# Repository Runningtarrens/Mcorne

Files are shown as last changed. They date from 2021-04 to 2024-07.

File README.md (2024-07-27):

# Mcorne legacy
28816_Mcorne_Banner

This is the Repository for a Magnetic Case for the Corne keyboard.



Content:

* Preface
* The case
* Bill of Materials
* How to print
* Files
* Tangented
* More Pics
* Legend
* License

# Preface

Rework of the documentation on a special page: https://runningtarrens.github.io/Mcorne/

If you build a lot of keyboards or repair them, you know the hassle of having to open the cases, screw/ unscrew and taking apart the whole thing everytime you need to reflow a solder point, an led or maybe even just reset the MCU. Also for any corne build youll need to have about 20 screws and 5 standoffs per half to just keep the halfs together. With the Mcorne you dont need to unscrew anything to access the PCB or any screw or standoff to use this case. The Case supports magnetic tenting legs and provides tenting holes for other tenting methods.

Feel free to join the Discord Server, if you have questions about the case or just want to have a chat: https://discord.gg/TRQFN7fyU5

# The Case

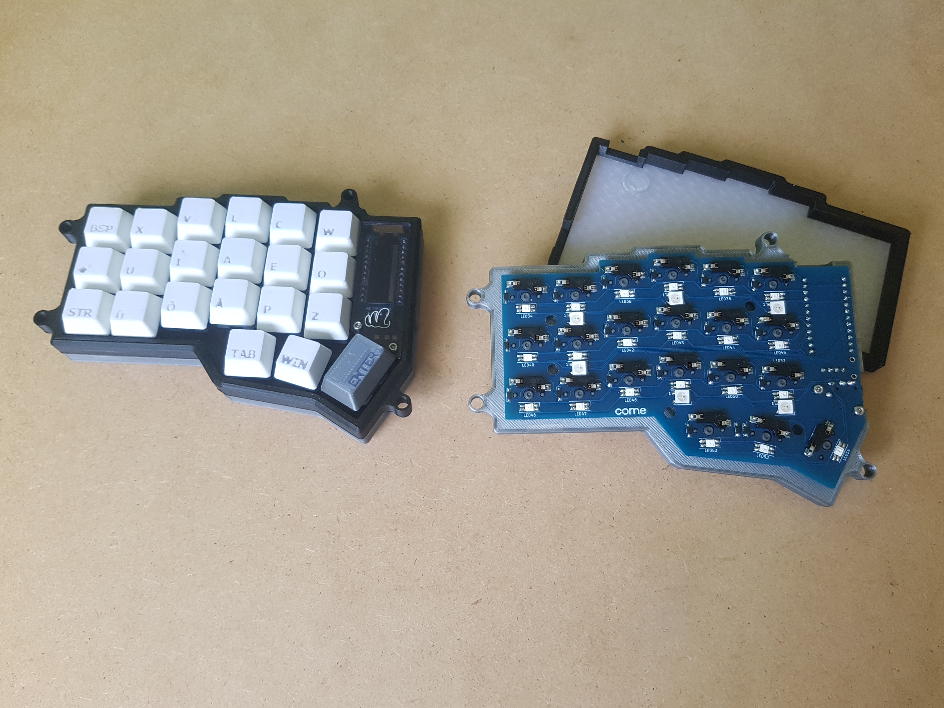
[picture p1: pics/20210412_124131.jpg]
MagneticCorne2

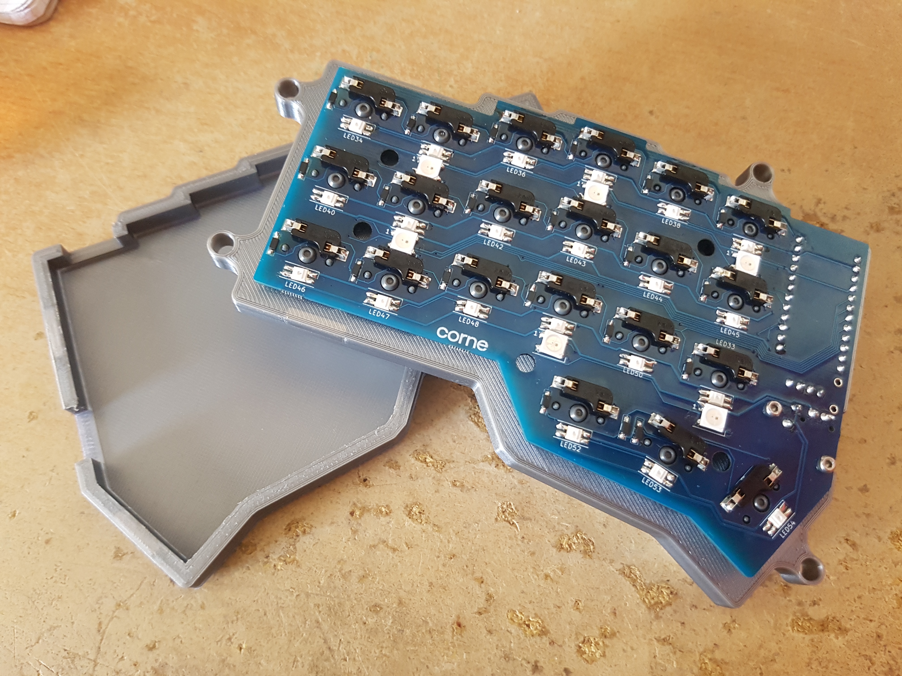
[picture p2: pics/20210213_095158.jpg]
MagneticCorne3

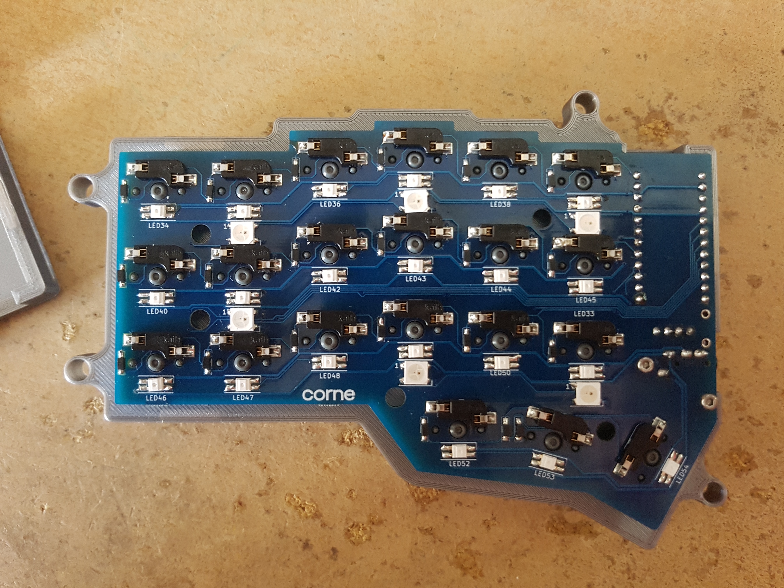
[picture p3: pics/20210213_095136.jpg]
MagneticCorne4


# Bill of Materials

To print this case youll need:
* about 120 gramms of Filament
* 16 Neodymium Magnets (14mm x 4mm x 2,5mm)
* (Optional) 4 Neodymium Magnets round (10mm x 1mm)

Getting the right Magnets can be Hard. Hier are a list of sources i could find or people provided me:

* Europe:
* USA: [Ebay.com](https://www.ebay.com/itm/255362762463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)

# How to print
 
 I always print in PLA, but you can use any filament for the case. ABS/ASA and Filament that require an enclosure are difficult to work with, because if you want to put the magnets in, you have to open the enclosure and might be having problems with warping or cracked prints because of that.

## Slicing

### Settings for the Print:

* 0.10 layer hight
* 3 Parimeters
* 3 Top and Bottom layers
* 15% Infill
* 205°C Filament temp
* 60°C Bed Temp

### Getting the magnets in

To get the magnets in, the M600 command is used. The printer makes a pause. While the print is pause, the magnets can be put into the pockets. Its important that you check and double check the polarity of the magnets, so that the halfs stick to each other and dont repel each other. The holes are tight but have a bit of tolerance, it can be a bit of work getting the magnets in, depending on how accurate your printer is.

### Top
The print is paused on the top half after the 42 layer or 4.2mm hight.
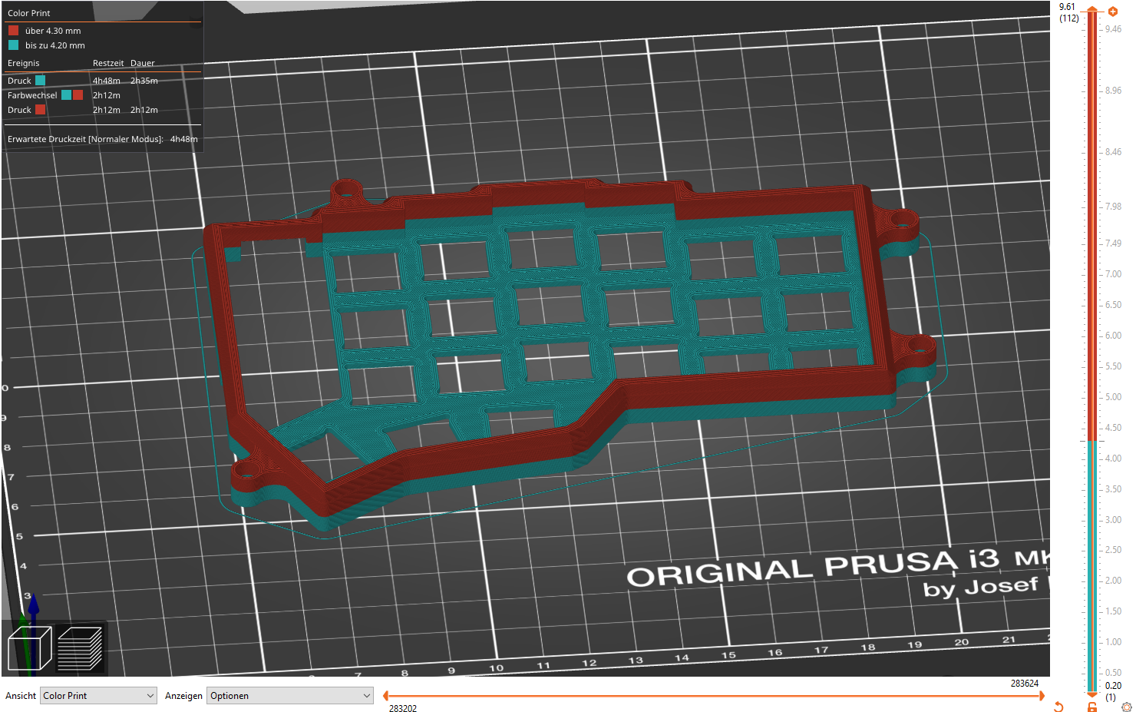
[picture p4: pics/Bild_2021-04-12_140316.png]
MagneticCorne5


#### Position of the Pockets for the Magnets
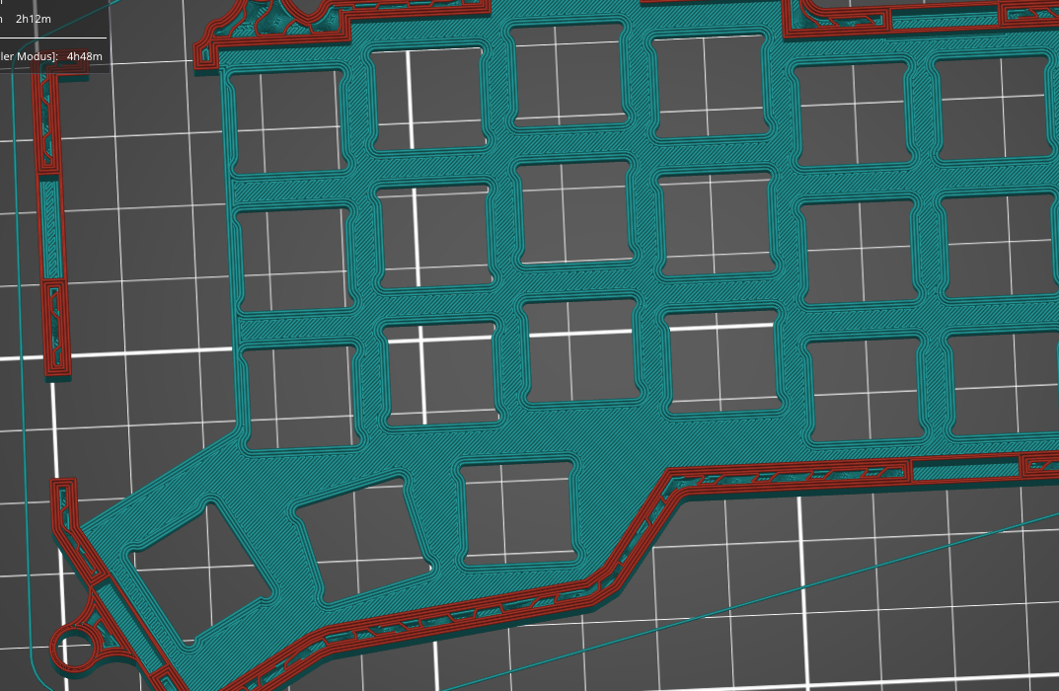
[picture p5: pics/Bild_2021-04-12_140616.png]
MagneticCorne6


### Bottom

The Bottom part is a bit more complex. It has, if you choose magnetig tenting and a transparent basis, 3 pauses. 2 to get the magnets in and 1 to just change the filament. If you dont want magnetic tenting and dont want another colour for the top part, youll only need one pause for the magnets.

#### Overview of the Part.

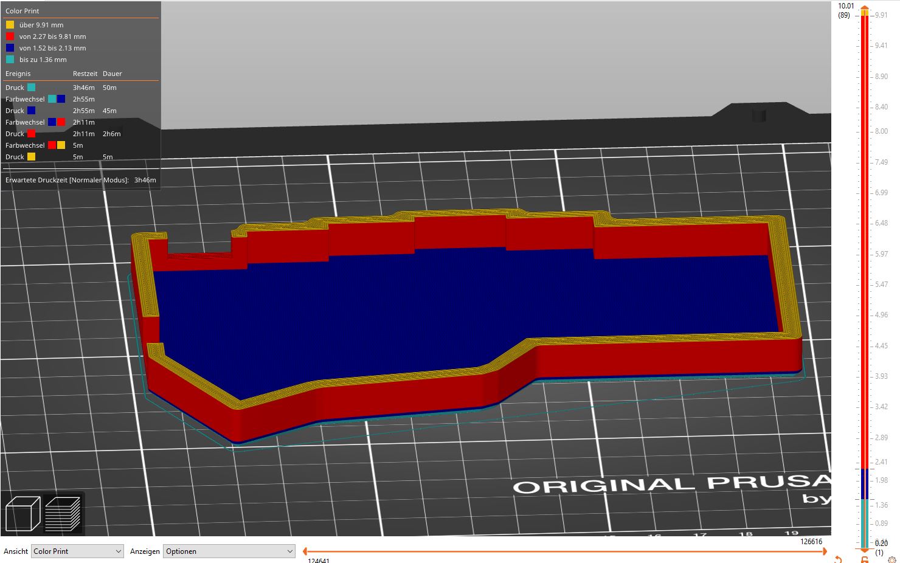
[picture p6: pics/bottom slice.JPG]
MagneticCorne7


#### First pause for the round magnets needed for the tenting

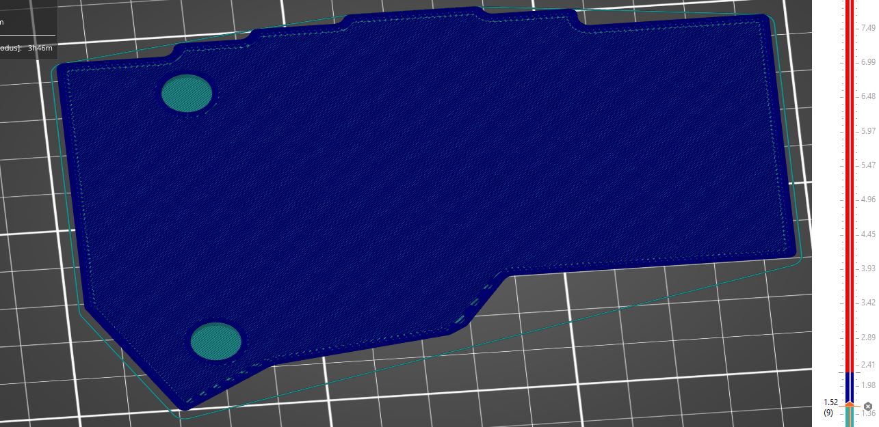
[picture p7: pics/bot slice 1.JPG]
MagneticCorne8


#### Second pause to change the filament (different colour)

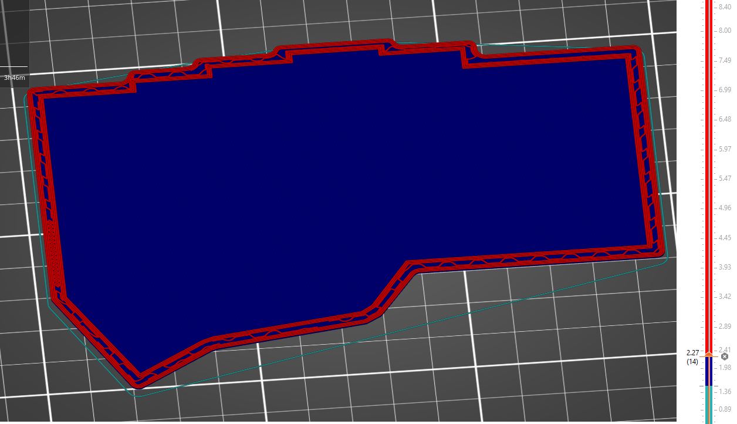
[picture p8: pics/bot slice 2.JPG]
MagneticCorne9


#### Third pause for the magnets to close the case

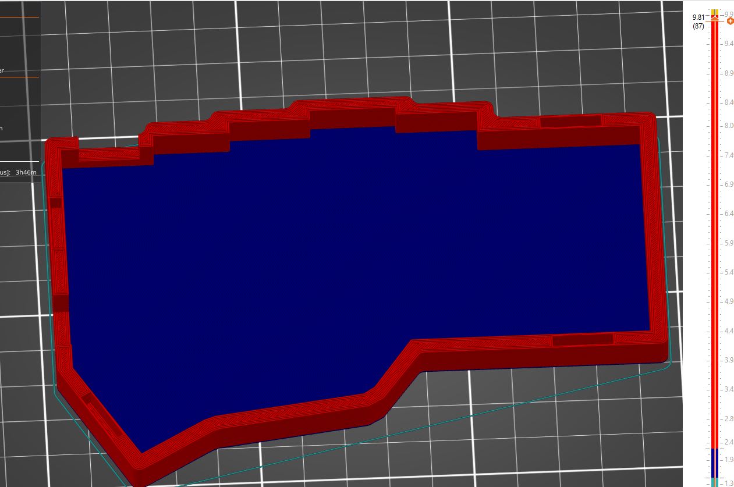
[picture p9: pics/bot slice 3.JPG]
MagneticCorne10


### Tenting Legs

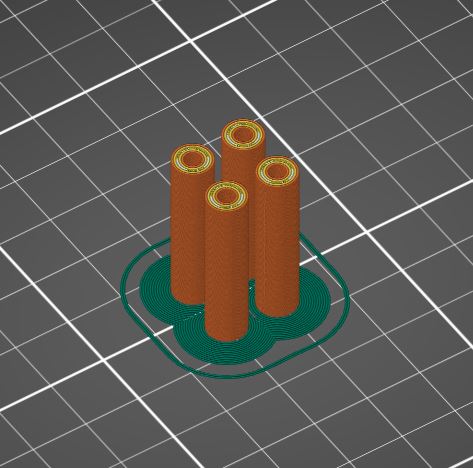
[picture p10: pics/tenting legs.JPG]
MagneticTentingLegs


Print 4 of them upright. But you need a prim to have enough surface that sticks to the build plate or it will get loose while printing.

# Files

## latest files

* corne split_bot_rechts_v4.stl
* corne split_top_right_reinforced_tentless_v4.stl
* corne split_top_right_reinforced_v4.stl
* magnet_tenting_30mm.stl

Version v4 is the latest for the case. I made some corrections so the inner keys ( T and Z dont scratch on the case).
I only uploaded the right side as .stl but you can just mirror it in your slicer software to get the left version of it. 

The .stl are to slice yourself. (There are also .3mf files which are already dialed in and provide the exact settings i use.).
The .3mf are in rework for now.

# Tangented

* Magnetic tenting legs - Added to the files directory
* Mcorne Travel Case - Added to the Travel Case directory
* Keycaps - soon

# More Pics

MagneticCornegif1
MagneticCornegif2

#### Bottom

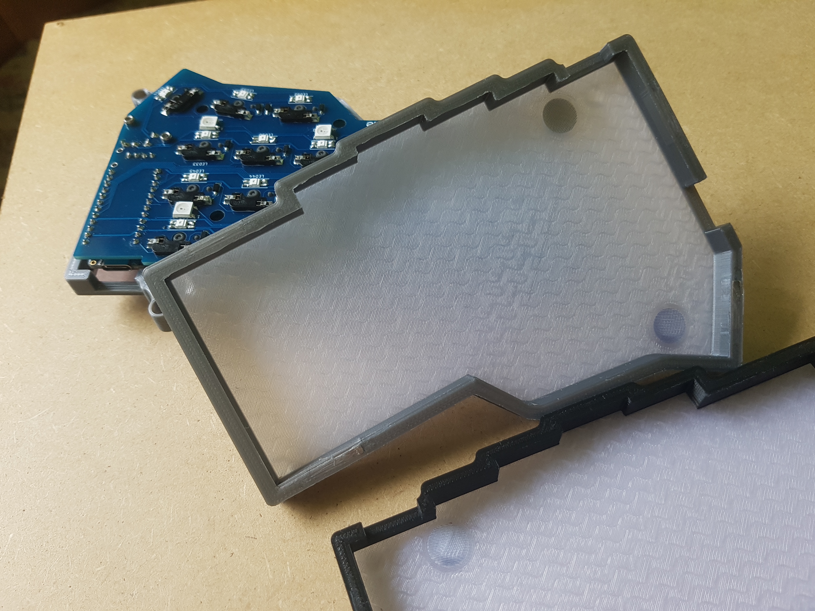
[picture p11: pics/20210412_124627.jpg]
MagneticCorne11


#### Top underside

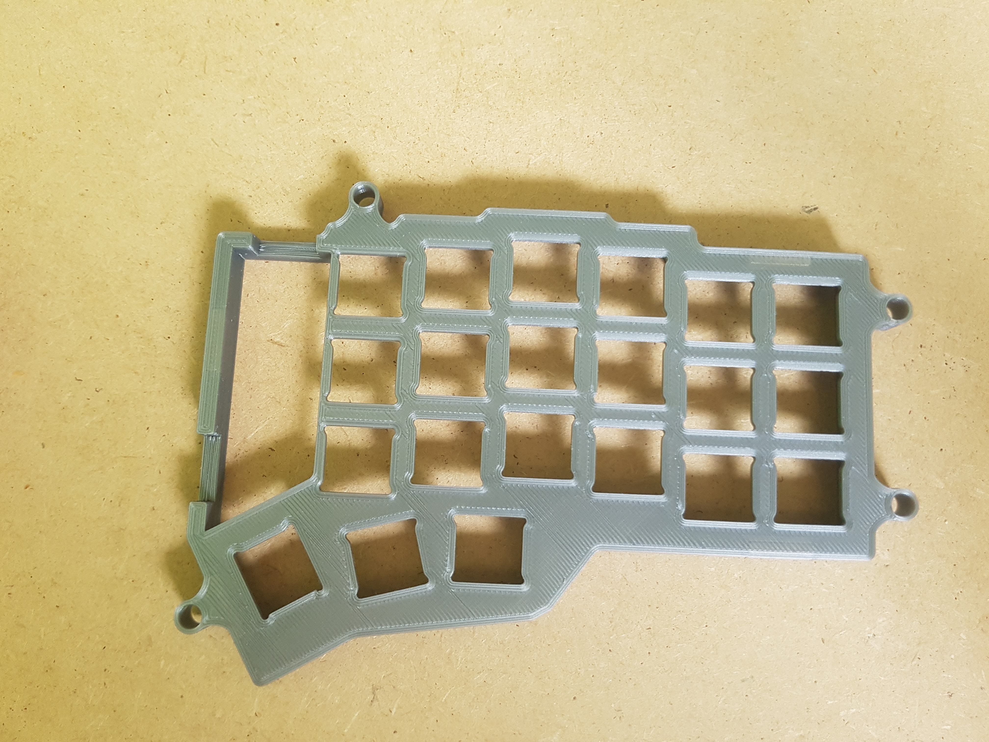
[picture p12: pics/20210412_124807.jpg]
MagneticCorne12


#### Top upside

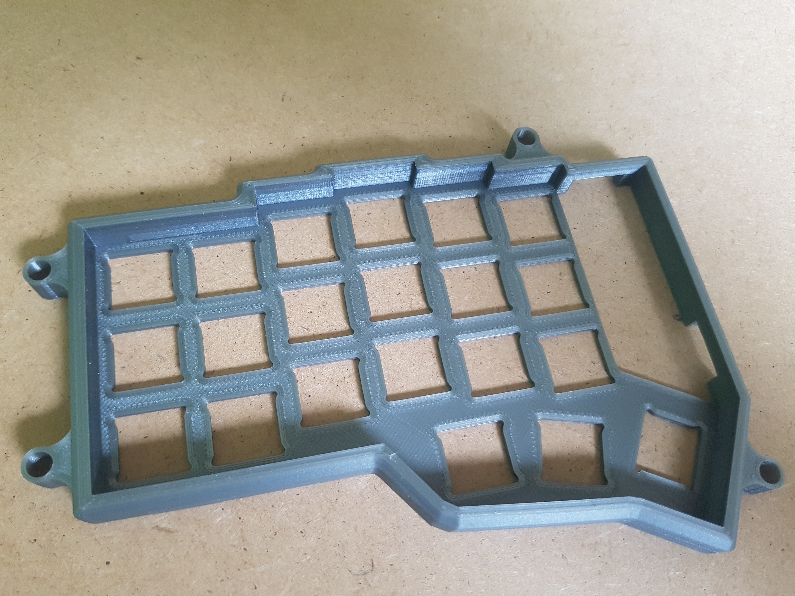
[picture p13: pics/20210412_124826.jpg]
MagneticCorne13


#### USB Port

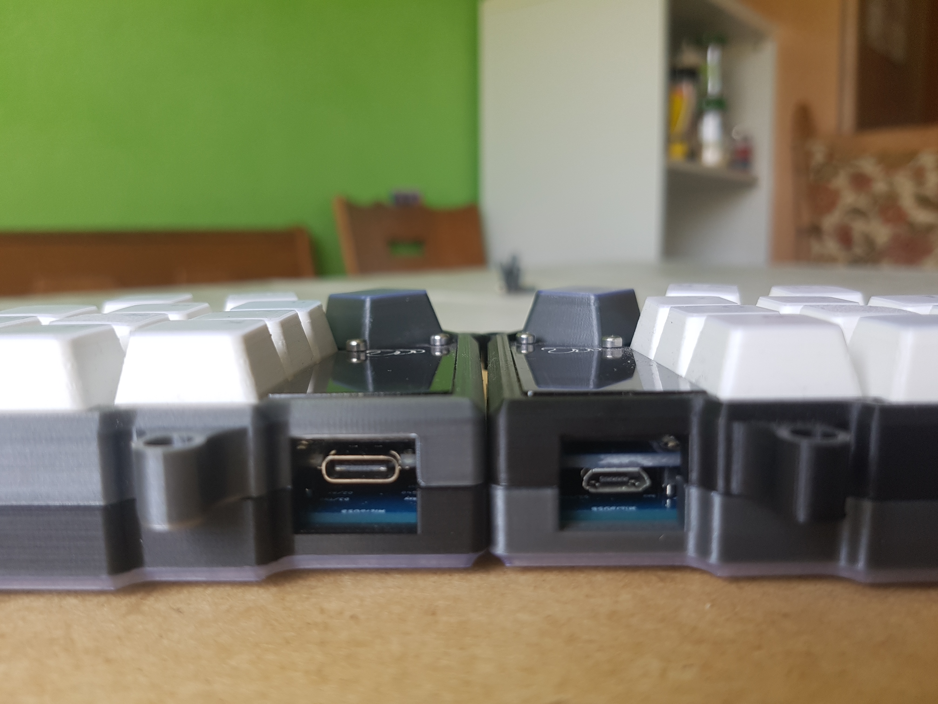
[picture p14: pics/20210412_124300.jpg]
MagneticCorne14


#### TRS Port

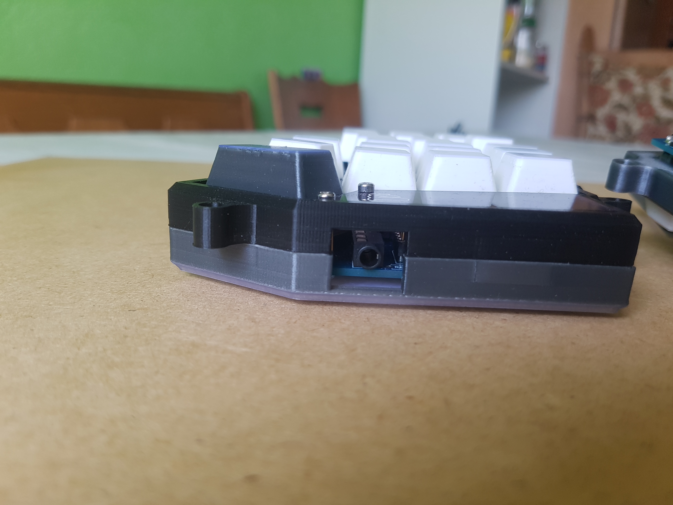
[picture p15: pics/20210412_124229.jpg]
MagneticCorne15


#### Detail view 

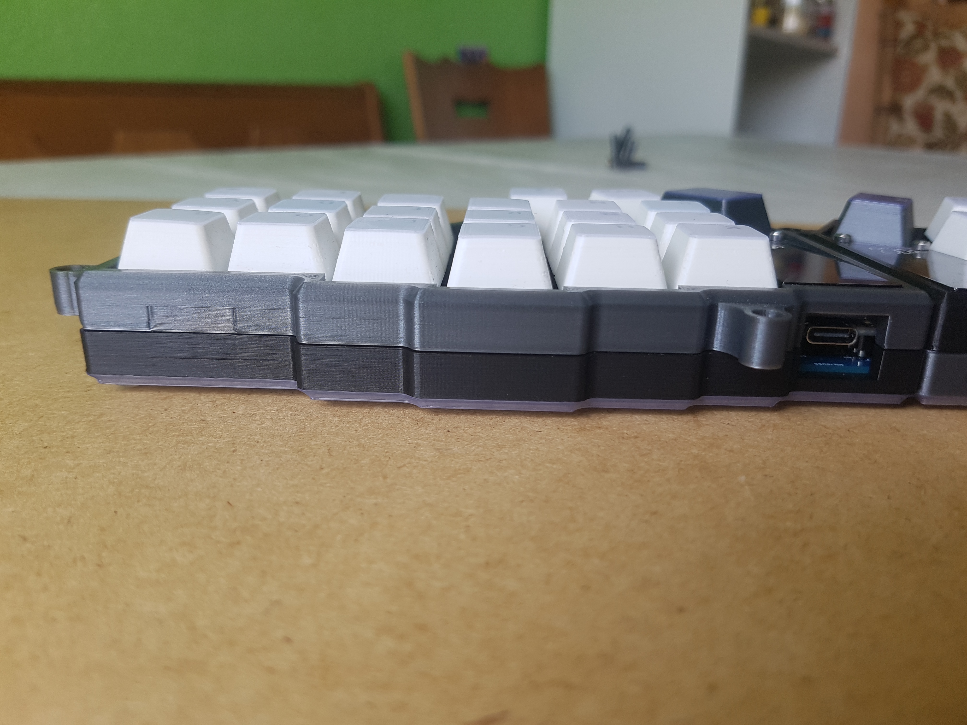
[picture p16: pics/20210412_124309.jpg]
MagneticCorne16


#### Detail view close up

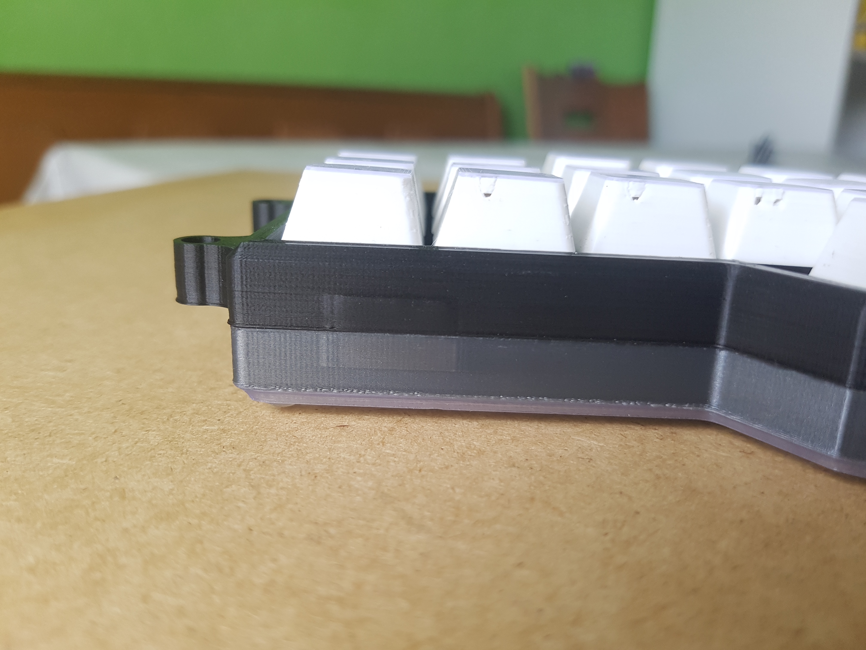
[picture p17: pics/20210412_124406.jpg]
MagneticCorne17


# Legend

* MCU = Microcontroller unit

# License

Print and modify all you want, but please dont sell my desgin (digital or printed).

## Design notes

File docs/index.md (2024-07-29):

# Welcome to Mcorne

28816_Mcorne_Banner

This is the Page for the Magnetic Case family for the Corne keyboard. There are different versions, so its easy to lose track of all the different versions or even to find the right one for your Corne and intented use case. So here is a overview with a quick summary of the features of the different cases and links to the different repositories.

## Preface

If you build a lot of keyboards or repair them, you know the hassle of having to open the cases, screw/ unscrew and taking apart the whole thing everytime you need to reflow a solder point, an led or maybe even just reset the MCU. Also for any corne build youll need to have about 20 screws and 5 standoffs per half to just keep the halfs together. The Mcorne doesnt need to be unscrewed to access the PCB or any screw or standoff to use this case. The Mcorne supports magnetic tenting legs and provides tenting holes for other tenting methods.

Feel free to join the Discord Server, if you have questions about the case or just want to have a chat: [Discord](https://discord.gg/TRQFN7fyU5)

!!! example "Disclaimer"

    To be able to print these cases you need a FDM printer. SLS or Resin printers wont work. Also your Printer firmware needs to support the pause feature to allow you to place the magnets in the pockets of the case. Most slicers and firewares use the M600 command.

## Commands

* `mkdocs new [dir-name]` - Create a new project.
* `mkdocs serve` - Start the live-reloading docs server.
* `mkdocs build` - Build the documentation site.
* `mkdocs -h` - Print help message and exit.

## Project layout

    mkdocs.yml    # The configuration file.
    docs/
        index.md  # The documentation homepage.
        ...       # Other markdown pages, images and other files.

This is the Repository for a Magnetic Case for the Corne keyboard.



This is the Repository for a Magnetic Case family for the Corne keyboard. There are 5 different version, so its easy to lose track of all the different versions or even to find the rigth one for your Corne and intented use case. So here is a overview with a quick summary of the features of the different cases and links to the different repositories.

Content:

* Preface
* The case
* Bill of Materials
* How to print
* Files
* Tangented
* More Pics
* Legend
* License

# Preface

Rework of the documentation on a special page: https://runningtarrens.github.io/Mcorne/

If you build a lot of keyboards or repair them, you know the hassle of having to open the cases, screw/ unscrew and taking apart the whole thing everytime you need to reflow a solder point, an led or maybe even just reset the MCU. Also for any corne build youll need to have about 20 screws and 5 standoffs per half to just keep the halfs together. With the Mcorne you dont need to unscrew anything to access the PCB or any screw or standoff to use this case. The Case supports magnetic tenting legs and provides tenting holes for other tenting methods.

Feel free to join the Discord Server, if you have questions about the case or just want to have a chat: https://discord.gg/TRQFN7fyU5

# The Case

MagneticCorne2
MagneticCorne3
MagneticCorne4

# Bill of Materials

To print this case youll need:
* about 120 gramms of Filament
* 16 Neodymium Magnets (14mm x 4mm x 2,5mm)
* (Optional) 4 Neodymium Magnets round (10mm x 1mm)

Getting the right Magnets can be Hard. Hier are a list of sources i could find or people provided me:

* Europe:
* USA: [Ebay.com](https://www.ebay.com/itm/255362762463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)

# How to print
 
 I always print in PLA, but you can use any filament for the case. ABS/ASA and Filament that require an enclosure are difficult to work with, because if you want to put the magnets in, you have to open the enclosure and might be having problems with warping or cracked prints because of that.

## Slicing

### Settings for the Print:

* 0.10 layer hight
* 3 Parimeters
* 3 Top and Bottom layers
* 15% Infill
* 205°C Filament temp
* 60°C Bed Temp

### Getting the magnets in

To get the magnets in, the M600 command is used. The printer makes a pause. While the print is pause, the magnets can be put into the pockets. Its important that you check and double check the polarity of the magnets, so that the halfs stick to each other and dont repel each other. The holes are tight but have a bit of tolerance, it can be a bit of work getting the magnets in, depending on how accurate your printer is.

### Top
The print is paused on the top half after the 42 layer or 4.2mm hight.
MagneticCorne5

#### Position of the Pockets for the Magnets
MagneticCorne6

### Bottom

The Bottom part is a bit more complex. It has, if you choose magnetig tenting and a transparent basis, 3 pauses. 2 to get the magnets in and 1 to just change the filament. If you dont want magnetic tenting and dont want another colour for the top part, youll only need one pause for the magnets.

#### Overview of the Part.

MagneticCorne7

#### First pause for the round magnets needed for the tenting

MagneticCorne8

#### Second pause to change the filament (different colour)

MagneticCorne9

#### Third pause for the magnets to close the case

MagneticCorne10

### Tenting Legs

MagneticTentingLegs

Print 4 of them upright. But you need a prim to have enough surface that sticks to the build plate or it will get loose while printing.

# Files

## latest files

* corne split_bot_rechts_v4.stl
* corne split_top_right_reinforced_tentless_v4.stl
* corne split_top_right_reinforced_v4.stl
* magnet_tenting_30mm.stl

Version v4 is the latest for the case. I made some corrections so the inner keys ( T and Z dont scratch on the case).
I only uploaded the right side as .stl but you can just mirror it in your slicer software to get the left version of it. 

The .stl are to slice yourself. (There are also .3mf files which are already dialed in and provide the exact settings i use.).
The .3mf are in rework for now.

# Tangented

* Magnetic tenting legs - Added to the files directory
* Mcorne Travel Case - Added to the Travel Case directory
* Keycaps - soon

# More Pics

MagneticCornegif1
MagneticCornegif2

#### Bottom

MagneticCorne11

#### Top underside

MagneticCorne12

#### Top upside

MagneticCorne13

#### USB Port

MagneticCorne14

#### TRS Port

MagneticCorne15

#### Detail view 

MagneticCorne16

#### Detail view close up

MagneticCorne17

# Legend

* MCU = Microcontroller unit

# License

Print and modify all you want, but please dont sell my desgin (digital or printed).

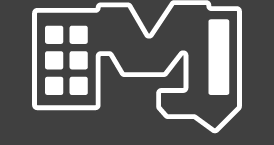
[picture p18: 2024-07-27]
docs/Mcorne_02_pure.png

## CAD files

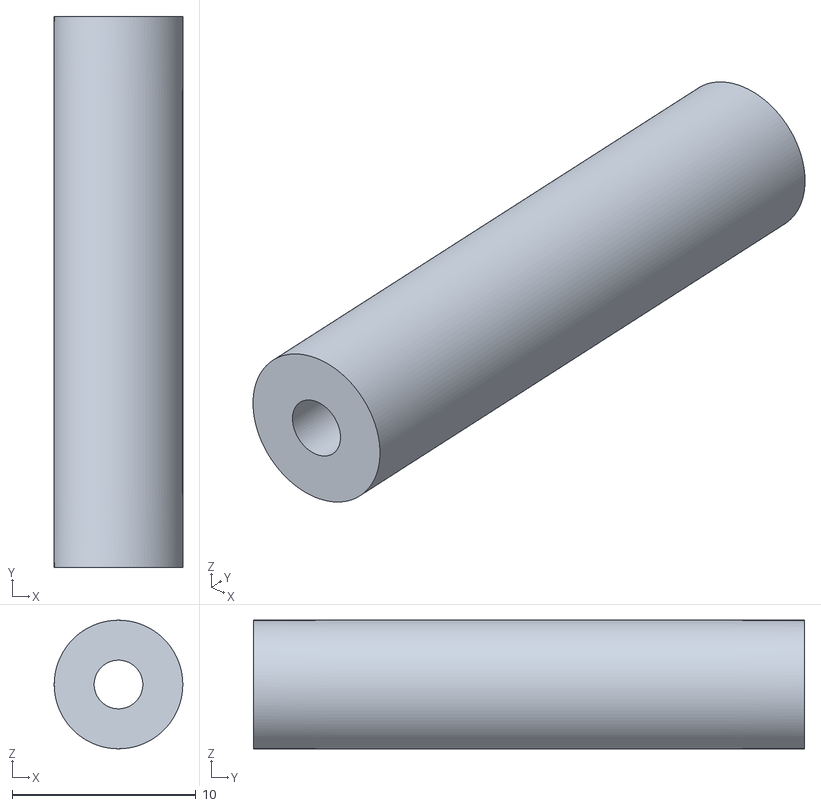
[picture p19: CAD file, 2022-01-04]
files/magnet_tenting_30mm.stl
7.00 x 30.0 x 7.00

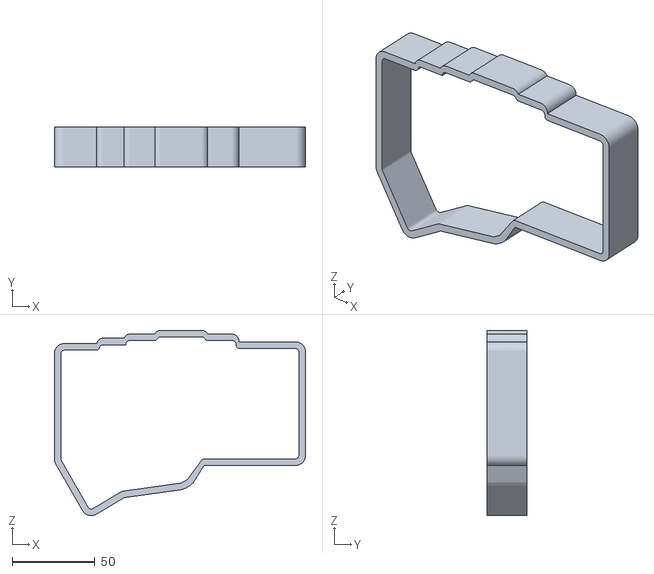
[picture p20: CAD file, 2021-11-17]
Travel Case/Travel_case_middle.stl
152.1 x 24.0 x 112.3

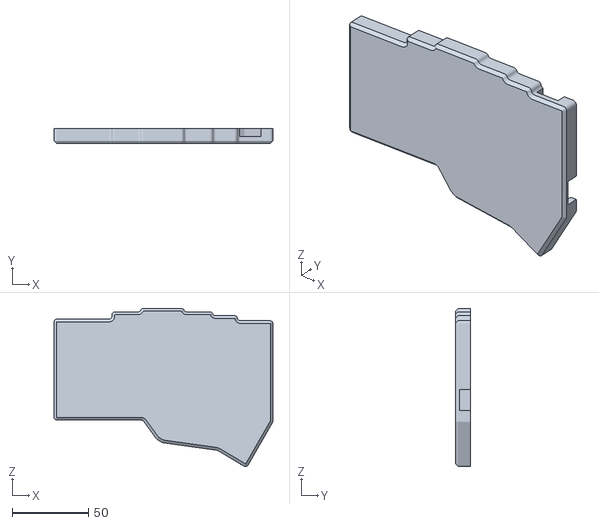
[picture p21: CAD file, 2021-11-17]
files/corne split_bot_rechts_v4.stl
143.5 x 10.0 x 103.6

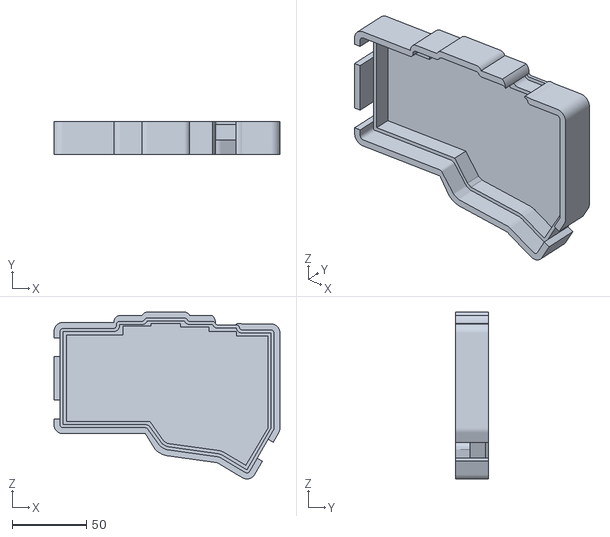
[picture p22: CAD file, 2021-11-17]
Travel Case/travel_case_top_right.stl
152.1 x 22.0 x 112.3

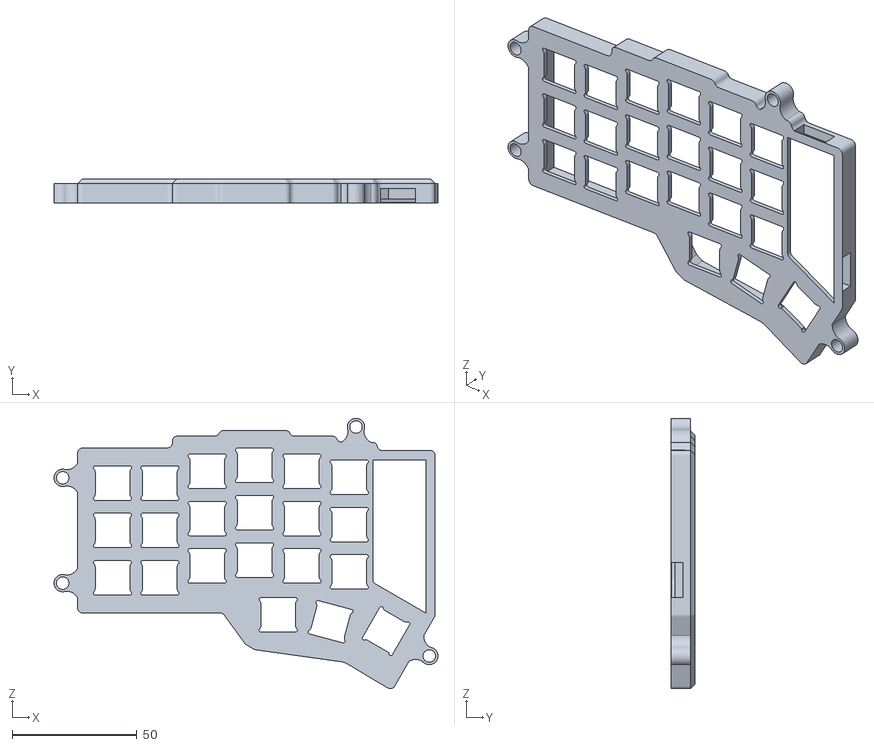
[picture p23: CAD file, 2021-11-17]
files/corne split_top_right_reinforced_v4.stl
154.1 x 9.60 x 108.5

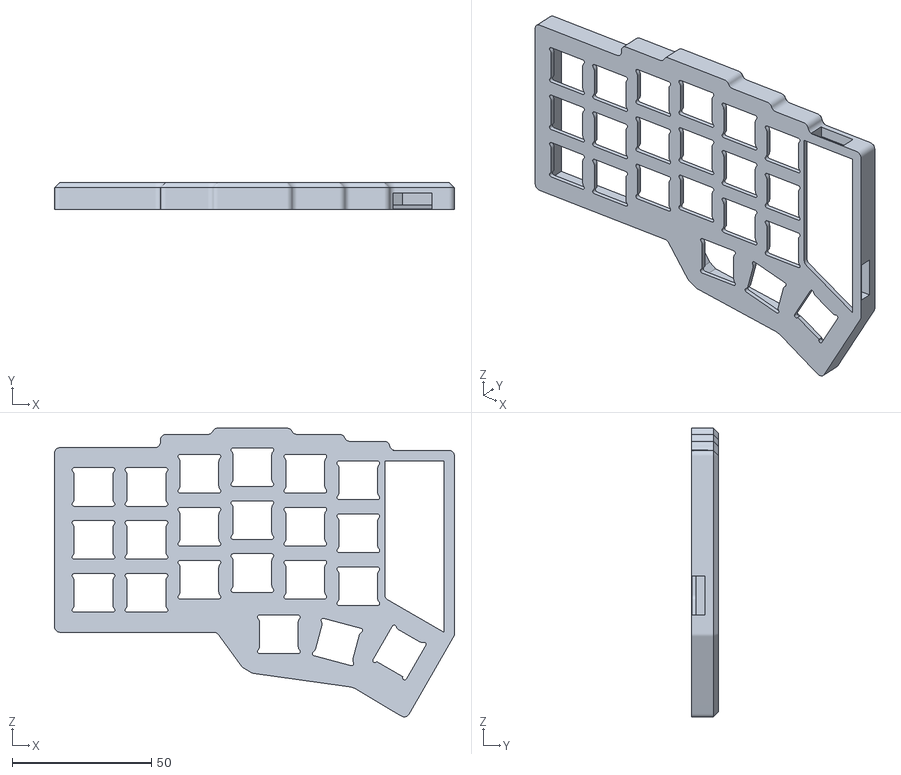
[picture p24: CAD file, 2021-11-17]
files/corne split_top_right_reinforced_tentless_v4.stl
143.5 x 9.60 x 103.6

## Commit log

2021-11-17 Add files via upload
    deleted the old stl and m3f files. added the newest version with an reinforcement for less warping on the top part. And an tentless option.
    [corne split_bot_rechts_v4.stl, corne split_top_right_reinforced_tentless_v4.stl, corne split_top_right_reinforced_v4.stl]
2024-07-26 Update README.md
    test for mkdoc material
